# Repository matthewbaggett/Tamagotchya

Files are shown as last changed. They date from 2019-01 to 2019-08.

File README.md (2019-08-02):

Tamagotchya
===========

A 2019 Tamagotchi clone using:
 * ESP 32 dual-core embedded wifi/bluetooth microcontroller
 * 4/8/16MB SPI flash on board
 * UT-0206-P05 monochrome oLED display
 * [ADXL345](References/ADXL345.pdf) Accellerometer
 * [USB C socket](References/XKB-U262-16XN-4BVC11_C319148.pdf) for charging and USB2.0 data
 * [CP2102N](References/SILICON-LABS-CP2102N-A01-GQFN20_C89049.pdf) Silicon Labs USB UART for interaction with a PCB 
 (and firmware loading)
 * [5 direction joypad](References/SF303GJ26-3.pdf) Up/Down/Left/Right/Click 
 * [TP4056](References/TP4056.pdf) 1A lithium battery charger for 300mAh-ish li-poly cell
 * [FS312](References/FS312.pdf) Battery over/under discharge protection, battery level monitoring using voltage divider and ESP's analog input.
 
## Render

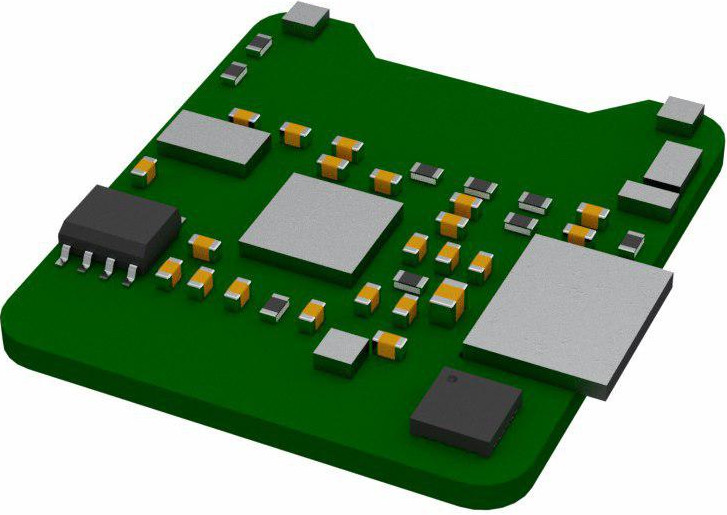
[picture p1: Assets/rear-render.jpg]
Render of rear


Render is of rear of device. Clearance at top of board is for solder-down connector of this oLED LCD, bent over and folded over the PCB:

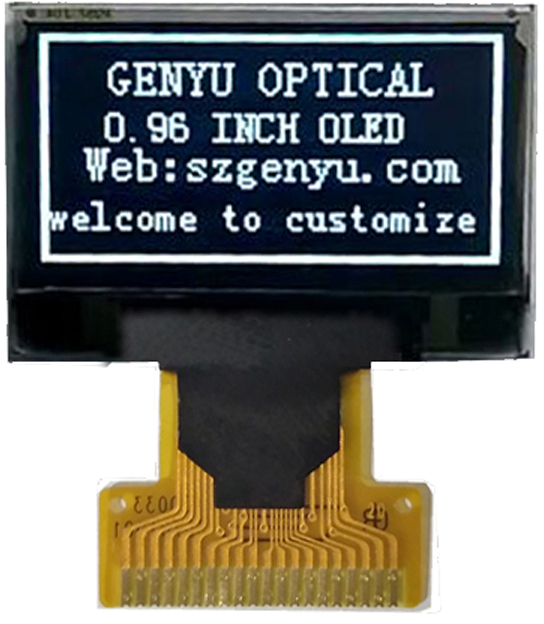
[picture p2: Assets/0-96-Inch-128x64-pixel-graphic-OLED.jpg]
oLED display


## PCB

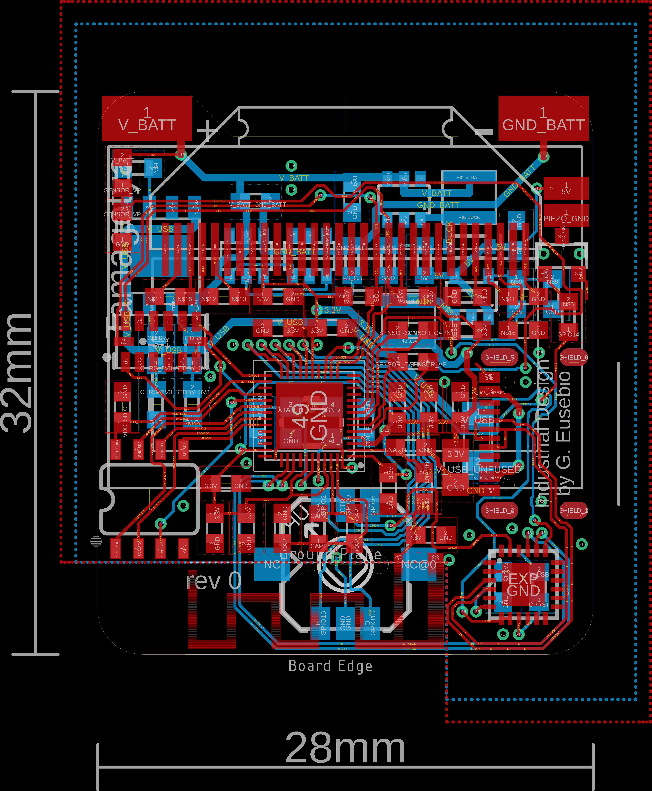
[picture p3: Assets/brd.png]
PCB


## Schematics
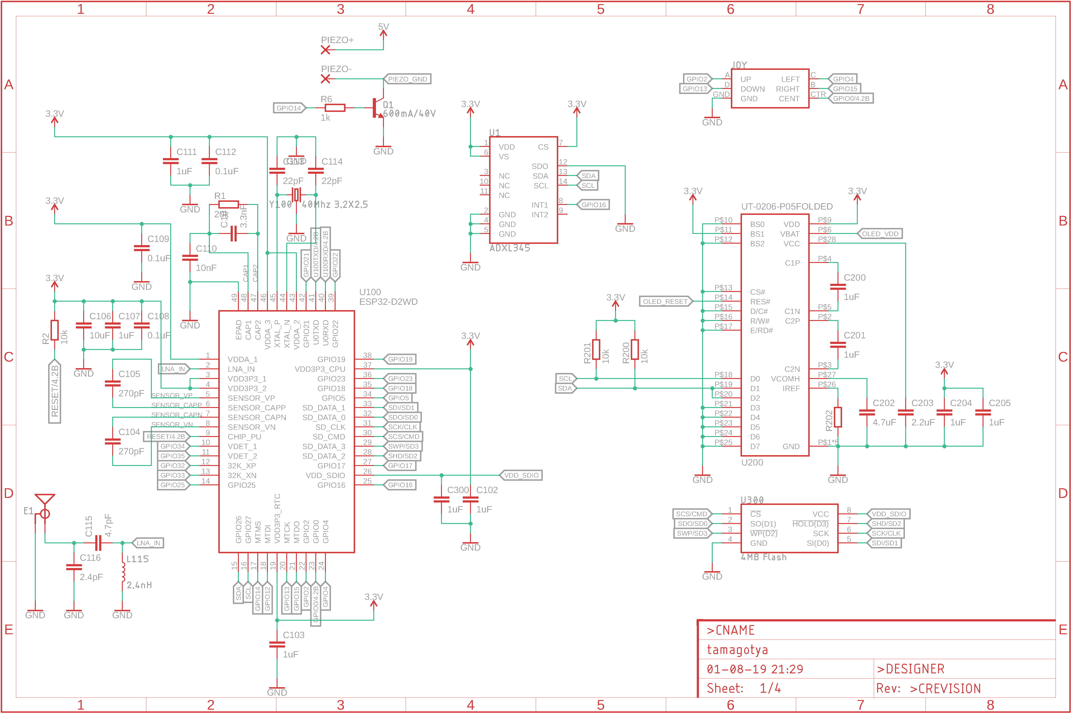
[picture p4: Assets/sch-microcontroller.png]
Microcontroller, Accellerometer and LCD

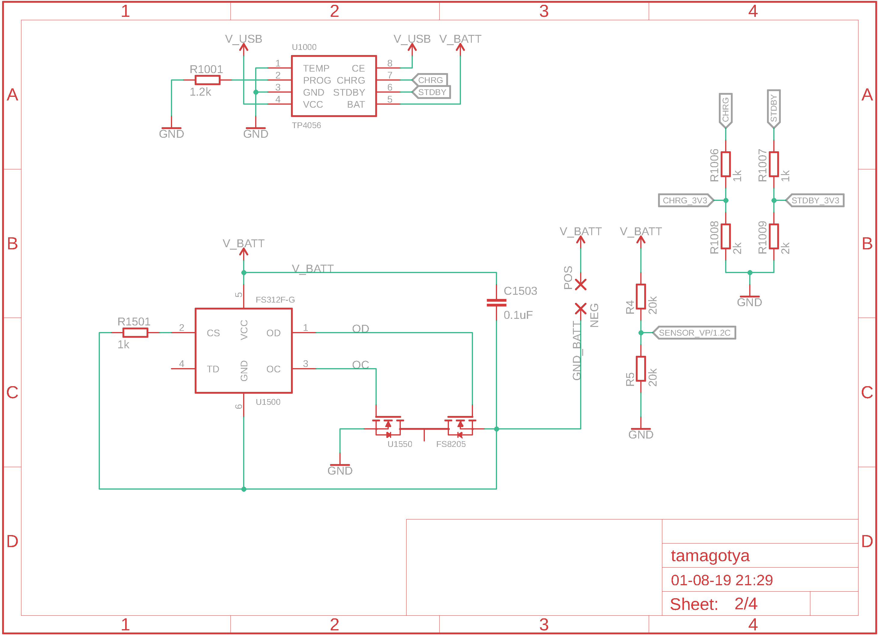
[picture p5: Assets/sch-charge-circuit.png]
Charge Circuit

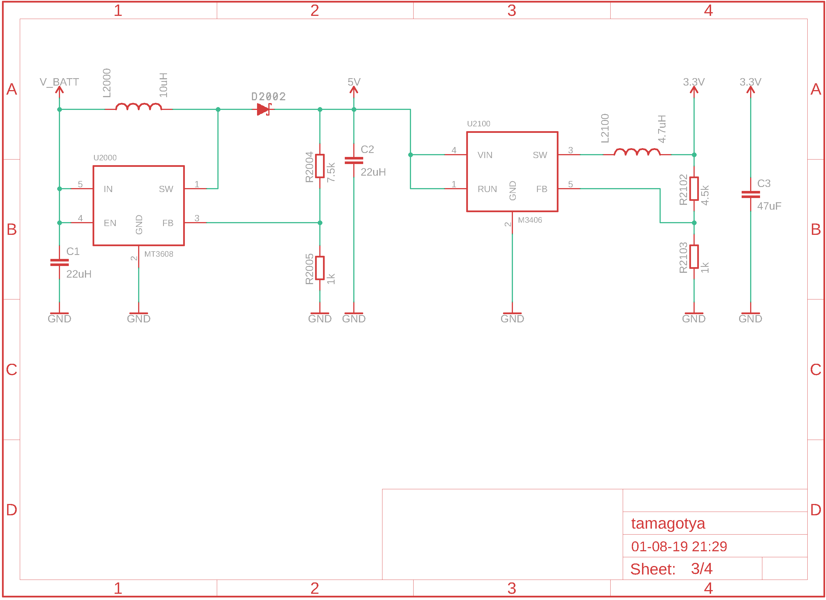
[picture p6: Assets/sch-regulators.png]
Regulators

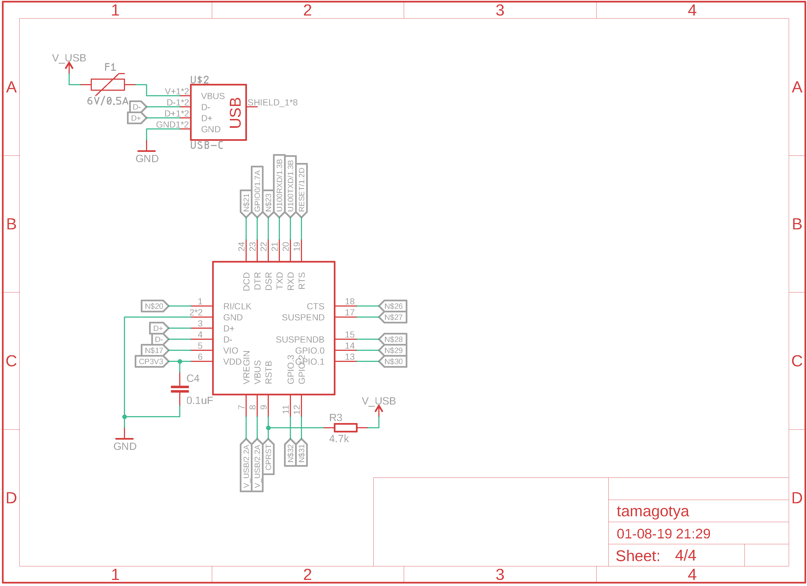
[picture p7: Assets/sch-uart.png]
UART


## License
This project is licensed under the The TAPR Open Hardware License.

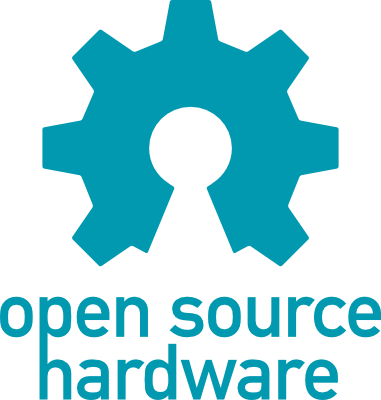
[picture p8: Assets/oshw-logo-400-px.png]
OSHW logo


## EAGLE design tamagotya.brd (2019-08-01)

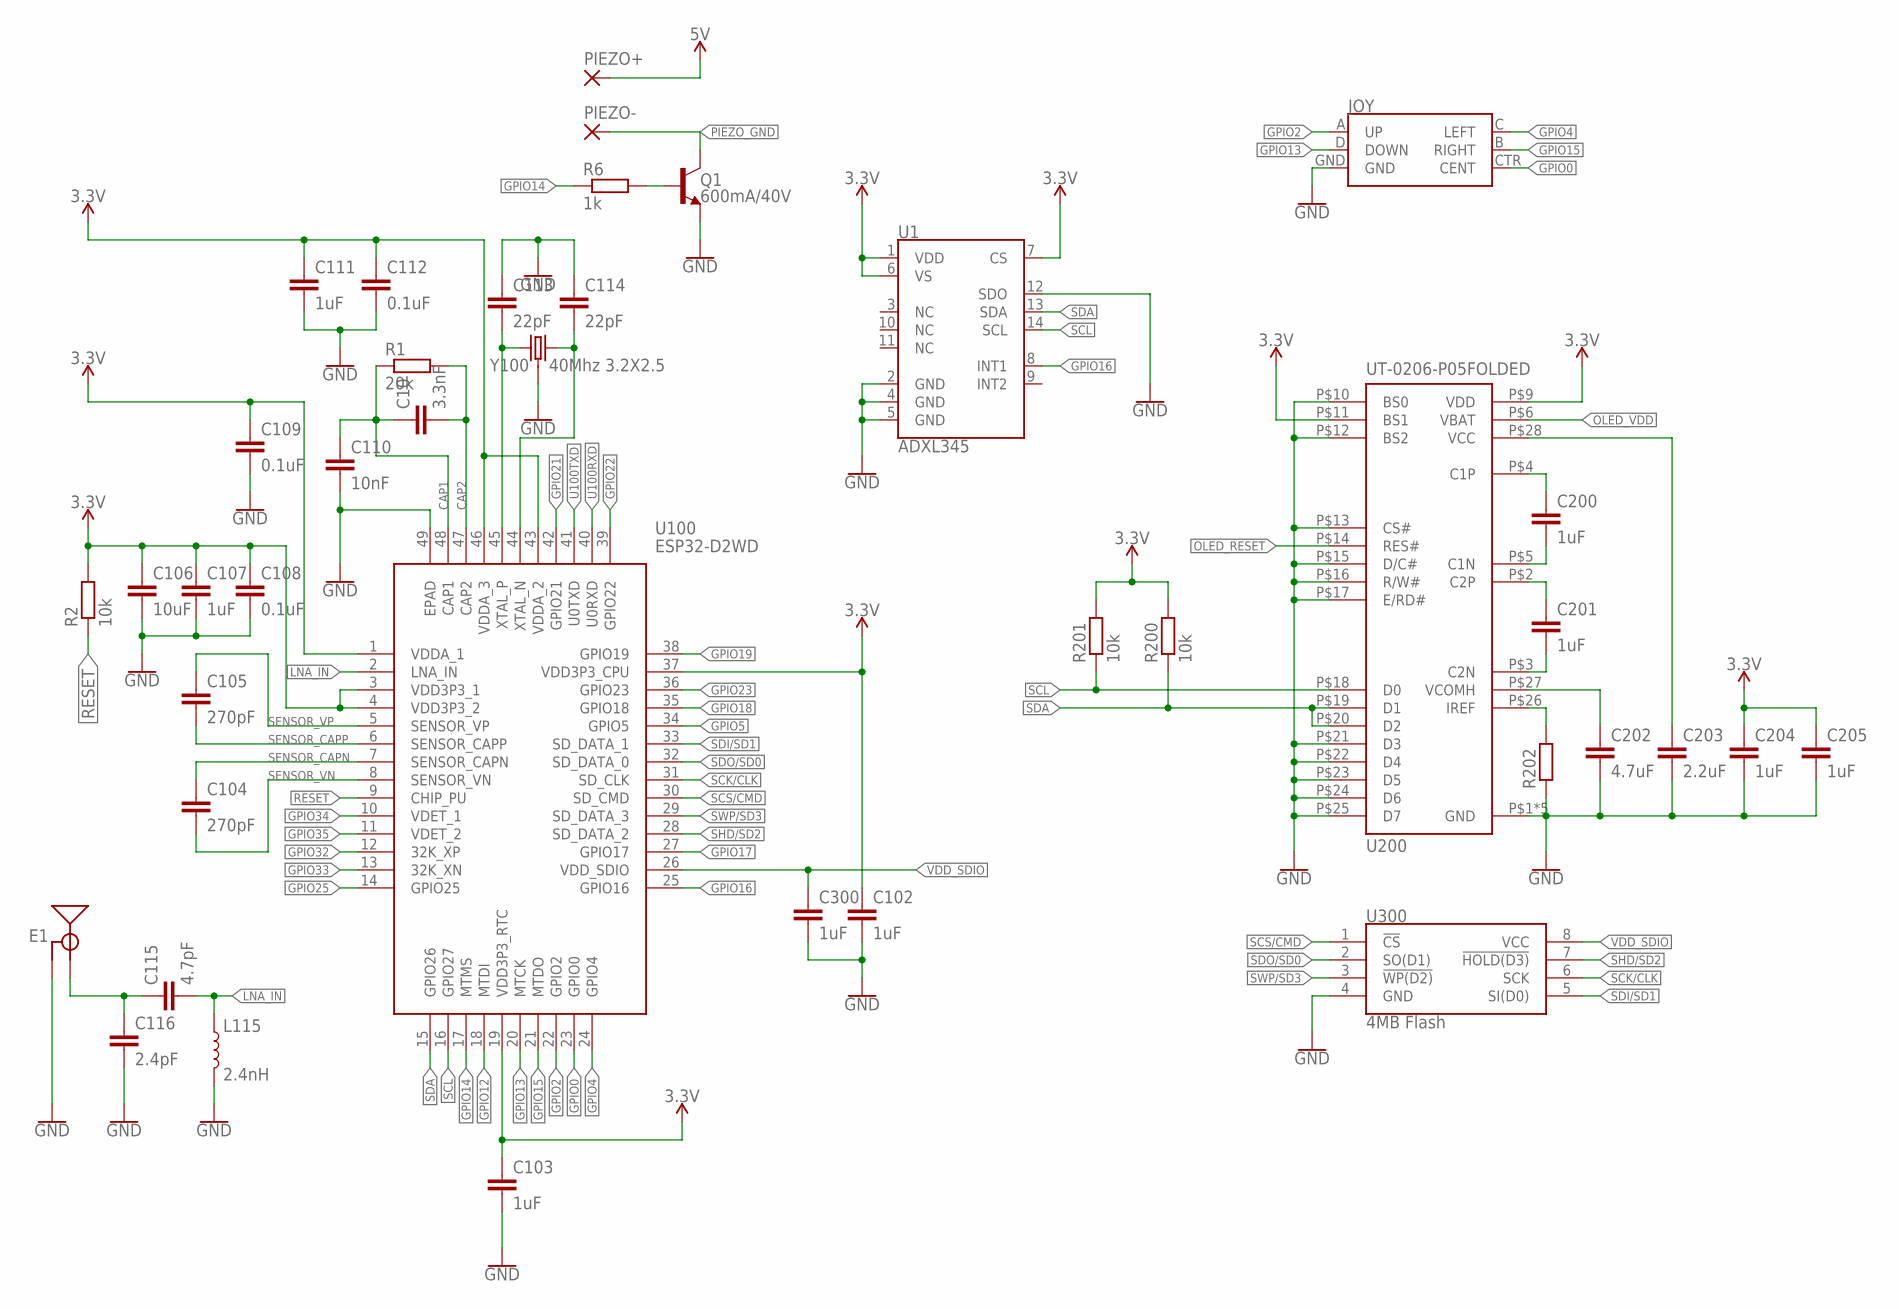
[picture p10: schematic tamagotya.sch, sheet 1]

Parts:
C10: 3.3nF; C0603
C102, C103, C107, C111, C200, C201, C204, C205, C300: 1uF; C0603
C104, C105: 270pF; C0603
C106: 10uF; C0603
C108, C109, C112: 0.1uF; C0603
C110: 10nF; C0603
C113, C114: 22pF; C0603
C115: 4.7pF; C0603
C116: 2.4pF; C0603
C202: 4.7uF; C0603
C203: 2.2uF; C0603
E1: ANTENNA-GROUNDEDTRACE-15.2MM; TRACE_ANTENNA_2.4GHZ_15.2MM
JOY: JOYSTICK_MINI
L115: 2.4nH; 0603
PIEZO+: WIREPADSMD1,27-254; SMD1,27-2,54
PIEZO-: WIREPADSMD1,27-254; SMD1,27-2,54
Q1: 600mA/40V; SOT23-3
R1: 20k; R0603
R2, R200, R201: 10k; R0603
R6: 1k; R0603
R202: R-EU_R0603; R0603
U1: ADXL345; LGA-14
U100: ESP32-D2WD; QFN35P500X500X90-49N
U200: UT-0206-P05FOLDED; UT-0206-P05-FOLD
U300: 4MB Flash; SO08
Y100: 40Mhz 3.2X2.5; CRYSTAL-SMD-3.2X2.5MM

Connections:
3.3V: C102.1, C103.1, C106.1, C107.1, C108.1, C109.1, C111.1, C112.1, C204.1, C205.1, R2.2, R200.2, R201.2, U1.1 (VDD), U1.6 (VS), U1.7 (CS), U100.1 (VDDA_1), U100.3 (VDD3P3_1), U100.4 (VDD3P3_2), U100.19 (VDD3P3_RTC), U100.37 (VDD3P3_CPU), U100.43 (VDDA_2), U100.46 (VDDA_3), U200.P$9 (VDD), U200.P$11 (BS1); also elsewhere on the board
5V: PIEZO+.1; also elsewhere on the board
CAP1: C10.1, C110.1, R1.1, U100.48 (CAP1)
CAP2: C10.2, R1.2, U100.47 (CAP2)
GND: C102.2, C103.2, C106.2, C107.2, C108.2, C109.2, C110.2, C111.2, C112.2, C113.1, C114.1, C116.2, C202.2, C203.2, C204.2, C205.2, C300.2, E1.GND, JOY.GND, L115.2, Q1.2 (E), R202.1, U1.2 (GND), U1.4 (GND), U1.5 (GND), U1.12 (SDO), U100.49 (EPAD), U200.P$1 (GND), U200.P$7 (GND), U200.P$8 (GND), U200.P$10 (BS0), U200.P$12 (BS2), U200.P$13 (CS#), U200.P$15 (D/C#), U200.P$16 (R/W#), U200.P$17 (E/RD#), U200.P$21 (D3), U200.P$22 (D4), U200.P$23 (D5), U200.P$24 (D6), U200.P$25 (D7), U200.P$29 (GND), U200.P$30 (GND), U300.4 (GND), Y100.2 (3), Y100.4 (3); also elsewhere on the board
GPIO0: JOY.CTR (CENT), U100.23 (GPIO0); also elsewhere on the board
GPIO2: JOY.A (UP), U100.22 (GPIO2)
GPIO4: JOY.C (LEFT), U100.24 (GPIO4)
GPIO5: U100.34 (GPIO5)
GPIO12: U100.18 (MTDI)
GPIO13: JOY.D (DOWN), U100.20 (MTCK)
GPIO14: R6.1, U100.17 (MTMS)
GPIO15: JOY.B (RIGHT), U100.21 (MTDO)
GPIO16: U1.8 (INT1), U100.25 (GPIO16)
GPIO17: U100.27 (GPIO17)
GPIO18: U100.35 (GPIO18)
GPIO19: U100.38 (GPIO19)
GPIO21: U100.42 (GPIO21)
GPIO22: U100.39 (GPIO22)
GPIO23: U100.36 (GPIO23)
GPIO25: U100.14 (GPIO25)
GPIO32: U100.12 (32K_XP)
GPIO33: U100.13 (32K_XN)
GPIO34: U100.10 (VDET_1)
GPIO35: U100.11 (VDET_2)
LNA_IN: C115.2, L115.1, U100.2 (LNA_IN)
unnamed: Q1.1 (B), R6.2
unnamed: C115.1, C116.1, E1.ANT (SIGNAL)
unnamed: R202.2, U200.P$26 (IREF)
unnamed: C202.1, U200.P$27 (VCOMH)
unnamed: C200.1, U200.P$4 (C1P)
unnamed: C200.2, U200.P$5 (C1N)
unnamed: C201.1, U200.P$2 (C2P)
unnamed: C201.2, U200.P$3 (C2N)
unnamed: C203.1, U200.P$28 (VCC)
OLED_RESET: U200.P$14 (RES#)
OLED_VDD: U200.P$6 (VBAT)
PIEZO_GND: PIEZO-.1, Q1.3 (C)
RESET: R2.1, U100.9 (CHIP_PU); also elsewhere on the board
SCK/CLK: U100.31 (SD_CLK), U300.6 (SCK)
SCL: R201.1, U1.14 (SCL), U100.16 (GPIO27), U200.P$18 (D0)
SCS/CMD: U100.30 (SD_CMD), U300.1 (!CS)
SDA: R200.1, U1.13 (SDA), U100.15 (GPIO26), U200.P$19 (D1), U200.P$20 (D2)
SDI/SD1: U100.33 (SD_DATA_1), U300.5 (SI(D0))
SDO/SD0: U100.32 (SD_DATA_0), U300.2 (SO(D1))
SENSOR_CAPN: C104.1, U100.7 (SENSOR_CAPN)
SENSOR_CAPP: C105.2, U100.6 (SENSOR_CAPP)
SENSOR_VN: C104.2, U100.8 (SENSOR_VN)
SENSOR_VP: C105.1, U100.5 (SENSOR_VP); also elsewhere on the board
SHD/SD2: U100.28 (SD_DATA_2), U300.7 (!HOLD(D3))
SWP/SD3: U100.29 (SD_DATA_3), U300.3 (!WP(D2))
U100RXD: U100.40 (U0RXD); also elsewhere on the board
U100TXD: U100.41 (U0TXD); also elsewhere on the board
VDD_SDIO: C300.1, U100.26 (VDD_SDIO), U300.8 (VCC)
XTAL_P: C113.2, U100.45 (XTAL_P), Y100.1
XTAN_N: C114.2, U100.44 (XTAL_N), Y100.3 (2)

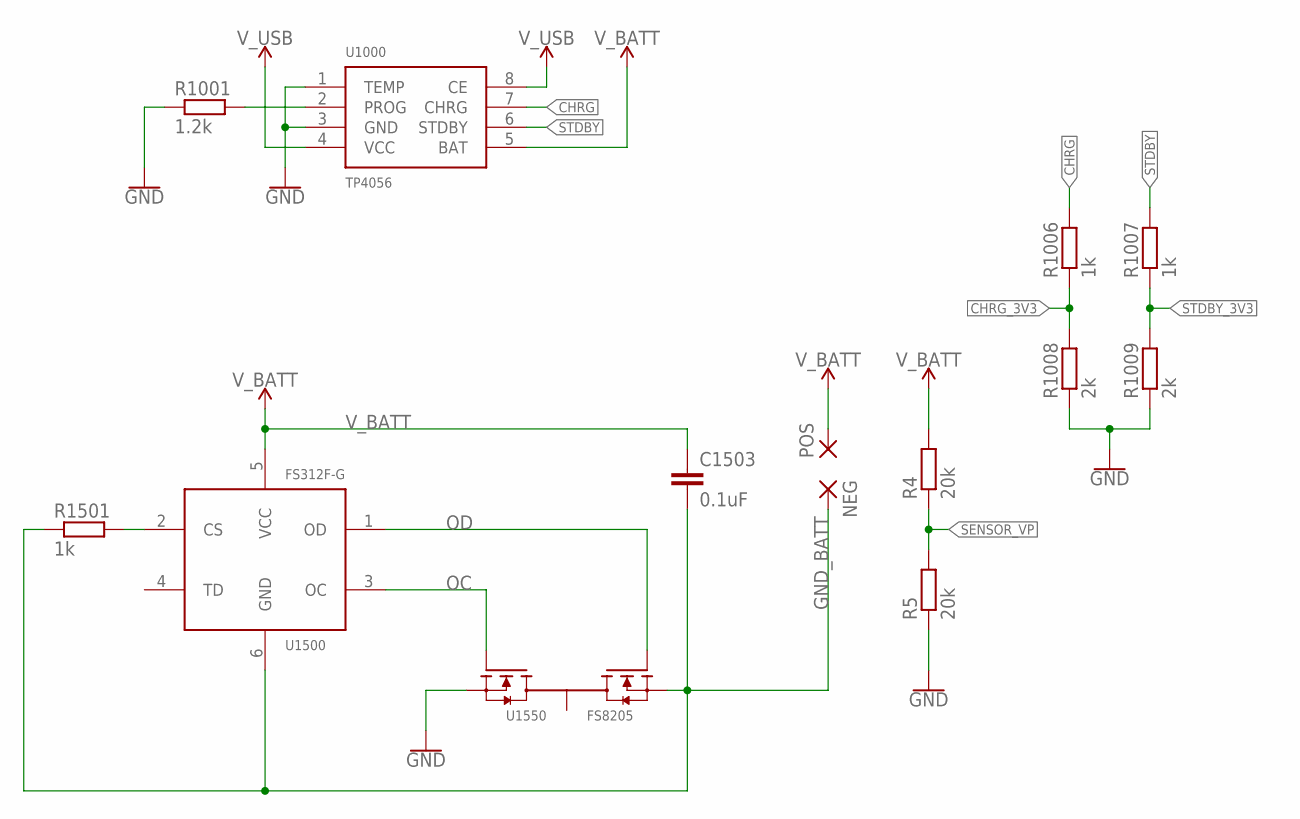
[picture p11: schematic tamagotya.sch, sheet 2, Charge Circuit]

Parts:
C1503: 0.1uF; C0603
NEG: SMD5; SMD2,54-5,08
POS: SMD5; SMD2,54-5,08
R4, R5: 20k; R0603
R1001: 1.2k; R0603
R1006, R1007, R1501: 1k; R0603
R1008, R1009: 2k; R0603
U1000: TP4056; SOP-8
U1500: FS312F-G; SOT23-6
U1550: FS8205; SOT23-6

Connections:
CHRG: R1006.2, U1000.7 (CHRG)
CHRG_3V3: R1006.1, R1008.2
FS_CS: R1501.2, U1500.2 (CS)
GND: R5.1, R1001.1, R1008.1, R1009.1, U1000.1 (TEMP), U1000.3 (GND), U1550.1 (S1); also elsewhere on the board
GND_BATT: C1503.2, NEG.1, R1501.1, U1500.6 (GND), U1550.3 (S2)
unnamed: R1001.2, U1000.2 (PROG)
OC: U1500.3 (OC), U1550.6 (G1)
OD: U1500.1 (OD), U1550.4 (G2)
SENSOR_VP: R4.1, R5.2; also elsewhere on the board
STDBY: R1007.2, U1000.6 (STDBY)
STDBY_3V3: R1007.1, R1009.2
V_BATT: C1503.1, POS.1, R4.2, U1000.5 (BAT), U1500.5 (VCC); also elsewhere on the board
V_USB: U1000.4 (VCC), U1000.8 (CE); also elsewhere on the board

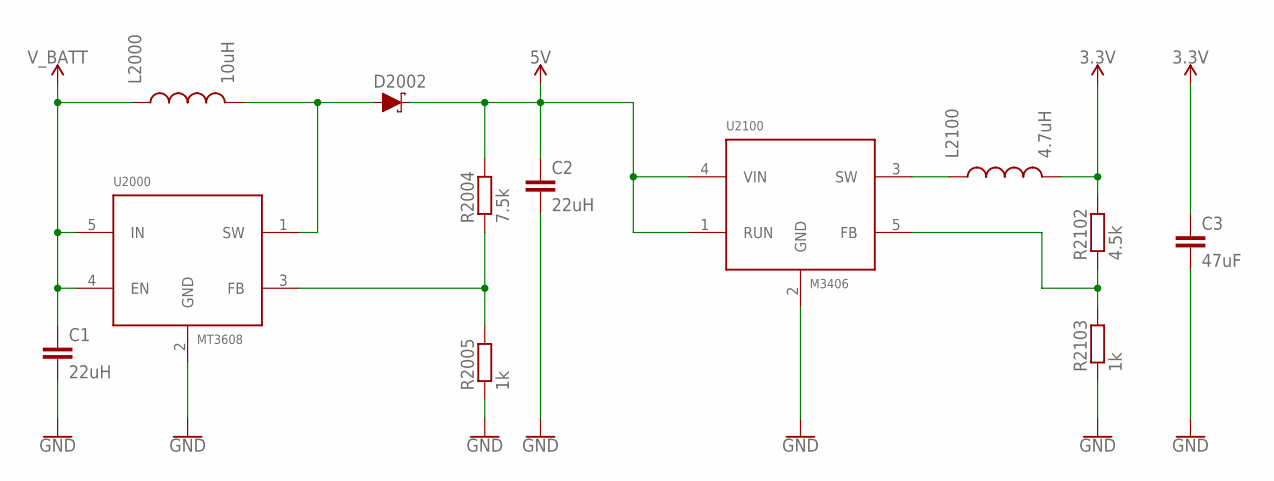
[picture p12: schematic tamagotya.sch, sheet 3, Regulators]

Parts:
C1, C2: 22uH; C0603
C3: 47uF; C0805
D2002: DIODE-SCHOTTKY-PMEG4005EJ; SOD-323
L2000: 10uH; INDUCTOR_3.0X3.0
L2100: 4.7uH; INDUCTOR_3.0X3.0
R2004: 7.5k; R0603
R2005, R2103: 1k; R0603
R2102: 4.5k; R0603
U2000: MT3608; SOT23-6
U2100: M3406; SOT23-5

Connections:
3.3V: C3.1, L2100.P$2 (2), R2102.2; also elsewhere on the board
5V: C2.1, D2002.C, R2004.2, U2100.1 (RUN), U2100.4 (VIN); also elsewhere on the board
BUCK: D2002.A, L2000.P$2 (2), U2000.1 (SW)
GND: C1.2, C2.2, C3.2, R2005.1, R2103.1, U2000.2 (GND), U2100.2 (GND); also elsewhere on the board
unnamed: R2004.1, R2005.2, U2000.3 (FB)
unnamed: L2100.P$1 (1), U2100.3 (SW)
unnamed: R2102.1, R2103.2, U2100.5 (FB)
V_BATT: C1.1, L2000.P$1 (1), U2000.4 (EN), U2000.5 (IN); also elsewhere on the board

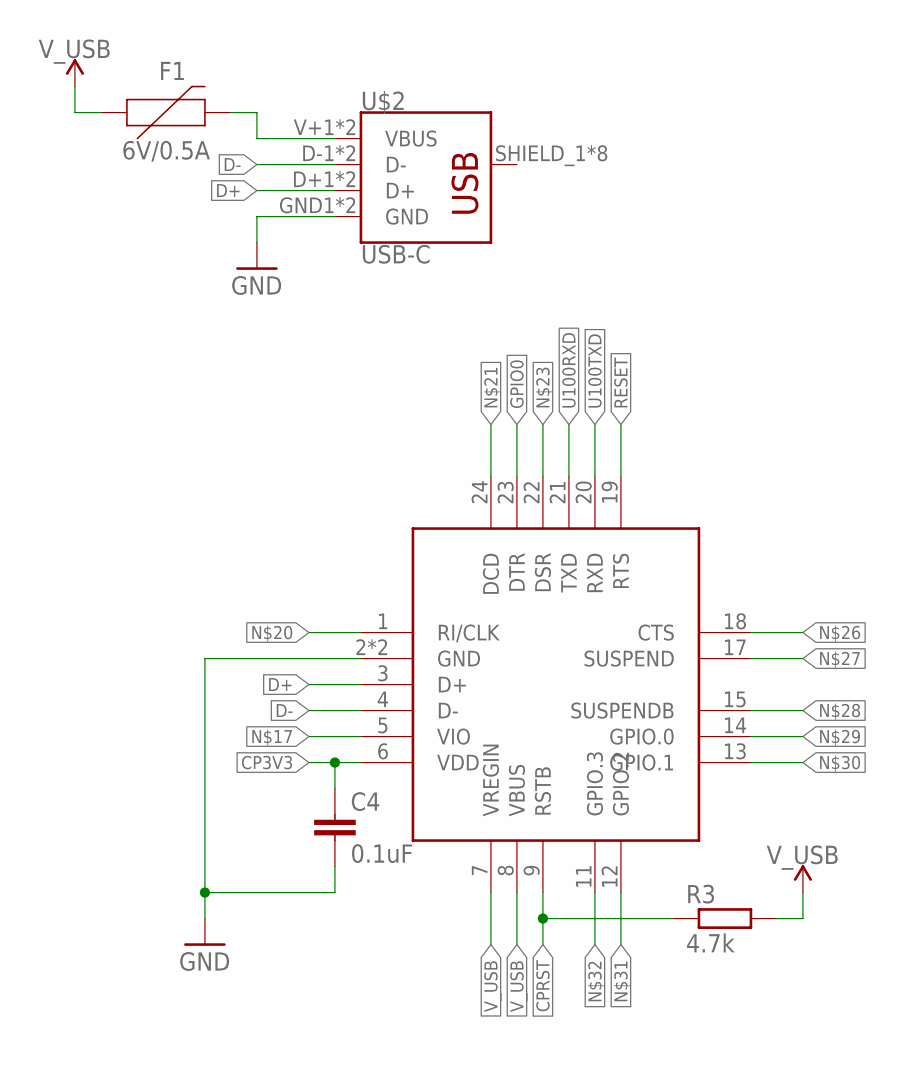
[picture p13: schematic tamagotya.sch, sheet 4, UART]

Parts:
C4: 0.1uF; C0603
F1: 6V/0.5A; 1206
R3: 4.7k; R0603
U$2: USB-C; USB_C-XKBENTERPRISEU262-16XN-4BVC11
U$3: CP2102N-QFN24; QFN24-4X4

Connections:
CP3V3: C4.1, U$3.6 (VDD)
CPRST: R3.1, U$3.9 (RSTB)
D+: U$2.D+1 (D+), U$2.D+2 (D+), U$3.3 (D+)
D-: U$2.D-1 (D-), U$2.D-2 (D-), U$3.4 (D-)
GND: C4.2, U$2.GND1 (GND), U$2.GND2 (GND), U$3.2 (GND), U$3.EXP (GND); also elsewhere on the board
GPIO0: U$3.23 (DTR); also elsewhere on the board
RESET: U$3.19 (RTS); also elsewhere on the board
U100RXD: U$3.21 (TXD); also elsewhere on the board
U100TXD: U$3.20 (RXD); also elsewhere on the board
V_USB: F1.1, R3.2, U$3.7 (VREGIN), U$3.8 (VBUS); also elsewhere on the board
V_USB_UNFUSED: F1.2, U$2.V+1 (VBUS), U$2.V+2 (VBUS)

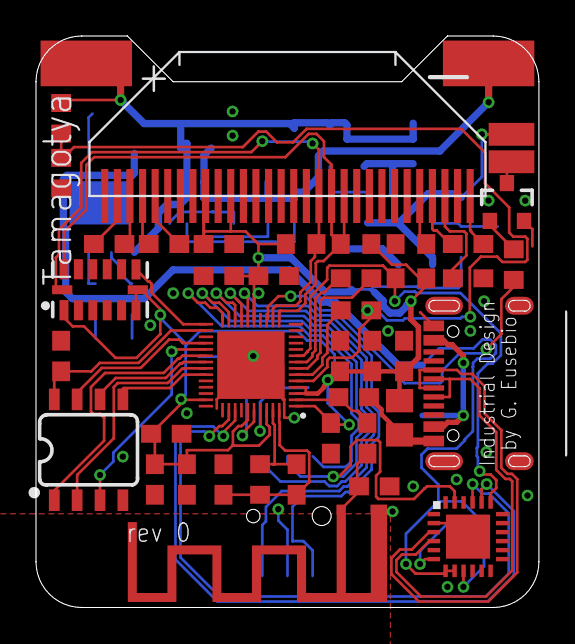
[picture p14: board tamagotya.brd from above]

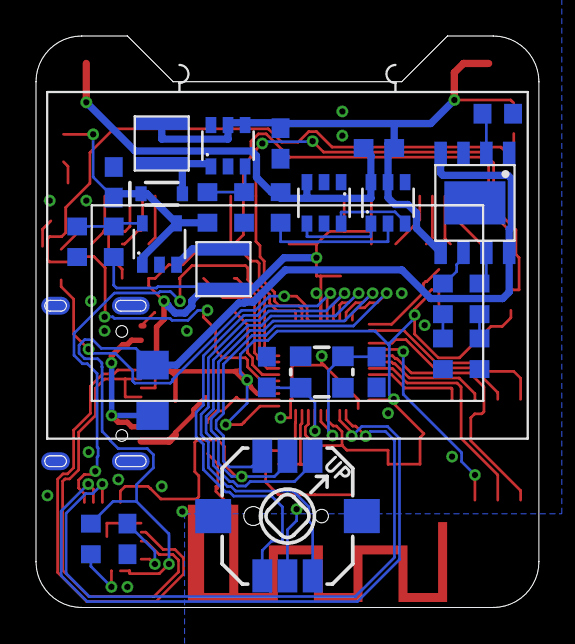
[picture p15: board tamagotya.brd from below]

Board: 2 copper layers, 27.9 x 31.8 mm, 71 parts (29 on the bottom side), 61 nets.

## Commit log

2019-01-24 Laid out, need to add charge/boost circuit and its basically done. Could do with a UART too.
    [tamagotya.brd, tamagotya.sch]
2019-01-24 Almost there. Mostly laid out. Just got CP2102 power to resolve.
    [tamagotya.brd, tamagotya.sch]
2019-01-25 CP2102 now has adequate power circuitry, I believe
    [tamagotya.brd, tamagotya.sch]
2019-01-25 Accellerometer ADXL345 with i2c + 1 interrupt.
    [tamagotya.brd, tamagotya.sch]
2019-01-25 Done: ADC sensing battery voltage.
    [tamagotya.brd, tamagotya.sch]
2019-01-25 Add a NPN transitor to drive a piezo speaker
    [tamagotya.brd, tamagotya.sch]
2019-01-25 Rejig to remove extra labels
    [tamagotya.brd]
2019-01-25 Fix collision between antenna and switch holes
    [tamagotya.brd]
2019-01-25 Futzing about with the edges of the ground plane layout
    [tamagotya.brd]
2019-08-01 Tamagotcha documentation
    [tamagotya.brd, tamagotya.sch]

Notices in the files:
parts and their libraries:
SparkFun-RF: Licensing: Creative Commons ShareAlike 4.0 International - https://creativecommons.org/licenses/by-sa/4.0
